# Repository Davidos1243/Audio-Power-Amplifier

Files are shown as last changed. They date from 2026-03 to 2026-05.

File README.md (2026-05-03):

# High-Fidelity Audio Power Amplifier (Class AB)





## 📌 Project Overview
This project involves the complete design, simulation, and PCB layout of a **Class AB audio power amplifier** designed specifically for high-frequency speakers (tweeters). The system is built around the Texas Instruments **LM3886** power amplifier IC and features active filtering using the **OPA2134** SoundPlus™ audio operational amplifiers.

### Key Features:
- **Output Power:** 60 W into an 8 Ω load.
- **Amplifier Class:** Class AB.
- **Active Crossover (Filters):**
  - High-Pass Filter (HPF) cutoff frequency: ~400 Hz.
  - Low-Pass Filter (LPF) cutoff frequency: ~20 kHz.
- **Input:** Standard 3.5mm audio jack (PC/Laptop sound card level).
- **Volume Control:** Integrated variable gain stage in the preamplifier.
- **Protection:** Built-in overvoltage, undervoltage, and SPiKe thermal protection (via LM3886).

---

## 📐 Design & Specifications

### Power Calculations
To achieve the target 60 W continuous output power for an 8 Ω speaker:
- Target speaker current: `I_rms ≈ 2.74 A`
- Target speaker voltage: `V_rms ≈ 21.91 V`
- Voltage gain required (for a 1 V input): `G ≈ 21.9 V/V`
- Power Supply: Symmetrical **±35 V** DC.
- Calculated maximum output power: `P_out ≈ 72 W` (providing safe headroom for the 60 W requirement).

### Component Selection
1. **Power Stage (LM3886):** Chosen for its high continuous average output power (up to 68 W), ultra-low distortion (0.03% THD+N), and robust SPiKe protection circuitry.
2. **Pre-amp & Active Filters (OPA2134):** Selected for its true FET-input, extremely low distortion (0.00008%), and excellent dynamic behavior tailored for high-end audio applications.

---

## 💻 LTspice Simulation
Before moving to physical design, the entire circuit was simulated in LTspice to verify stability, frequency response, and power efficiency.

### 1. Frequency Filters (Bode Analysis)
- **High-Pass Filter (Sallen-Key):** 2nd-order active filter. Simulated cutoff frequency (`f_c`) ≈ **399.6 Hz** with a stopband roll-off of -40 dB/decade.
- **Low-Pass Filter:** 2nd-order active filter. Simulated cutoff frequency (`f_c`) ≈ **20.8 kHz** with a stopband roll-off of -40 dB/decade.

### 2. Transient & Power Analysis
- Simulated using a 1 kHz sine wave input.
- Input voltage: `1 V` | Output voltage: `~32 V` (peak).
- Verified the required 60 W average power on the 8 Ω load.
- **Calculated Efficiency:** `η ≈ 71%` (at maximum power output).

---

## 🖨️ PCB Design (KiCAD)
The schematic was transferred to KiCAD for PCB layout. The physical layout was designed with strict analog audio guidelines:
- **Signal Flow:** Left-to-right signal path to prevent interference.
- **Trace Widths:** Calculated and adjusted for high-current power and output lines.
- **Grounding:** Large copper ground planes implemented to minimize noise and improve shielding.
- **Thermal Management:** Dedicated space and mounting holes provided for the LM3886 heatsink.
- **I/O:** Strategic placement of the 3.5mm jack, power terminals, and output connectors at the board edges.
- Form Factor: 2-layer FR-4 board, 50.8 x 48.26 mm.

---

## 🛠️ Bill of Materials (BOM)
Key components used in this design (SMD 0805 for passives to maintain a compact footprint):
- **ICs:** 1x LM3886, 2x OPA2134
- **Capacitors (SMD):** 1 nF, 2.2 nF, 100 nF, 120 nF, 220 nF, 1 µF
- **Resistors (SMD):** 100 Ω, 366.9 Ω, 500 Ω, 1.8 kΩ, 2 kΩ, 3.9 kΩ, 6.8 kΩ
- **Connectors:** 3.5mm Audio Jack, Molex SL Screw Terminals
- **Controls:** 10 kΩ THT Potentiometer for volume control

## 📦 Manufacturing
The PCB was cost-analyzed and prepared for fabrication using **JLCPCB** specifications:
- **Material:** FR4-TG135 (1.6mm thickness)
- **Copper Weight:** 1 oz
- **Surface Finish:** HASL

---

## 👨‍💻 Author
**Davyd Tkalich**  
*Electrical and Computer Engineering | Hardware Design Enthusiast*  
[LinkedIn](https://linkedin.com/in/davyd-tkalich-41916b277) | Edmonton, AB, Canada

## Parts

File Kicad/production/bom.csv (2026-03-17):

Designator | Footprint | Quantity | Value | LCSC Part #
C1, C10, C7, C9 | 0805 | 4 | 1u
C2 | 0805 | 1 | 1n
C3 | 0805 | 1 | 2.2n
C4 | 0805 | 1 | 220n
C5 | 0805 | 1 | 120n
C6, C8 | 0805 | 2 | 100n
J1 | Jack_3.5mm_CUI_SJ1-3533NG_Horizontal | 1 | AudioJack2
J2, J3 | Molex_SL_171971-0003_1x03_P2.54mm_Vertical | 2 | Screw_Terminal_01x03
J4 | Molex_SL_171971-0002_1x02_P2.54mm_Vertical | 1 | Screw_Terminal_01x02
R1, R8 | 0805 | 2 | 2k
R11 | 0805 | 1 | 8
R2 | 0805 | 1 | 0.5k
R3, R6 | 0805 | 2 | 3.9k
R4 | 0805 | 1 | 6.8k
R5 | 0805 | 1 | 1.8k
R7 | 0805 | 1 | 366.9
R9 | 0805 | 1 | 100
RV1 | Potentiometer_ACP_CA14-H4_Horizontal | 1 | 10k
U1, U3 | SOIC-8-1EP_3.9x4.9mm_P1.27mm_EP2.29x3mm | 2 | OPA2134
U2 | TO-220F-11_P3.4x5.08mm_StaggerOdd_Lead5.08mm_Vertical | 1 | LM3886

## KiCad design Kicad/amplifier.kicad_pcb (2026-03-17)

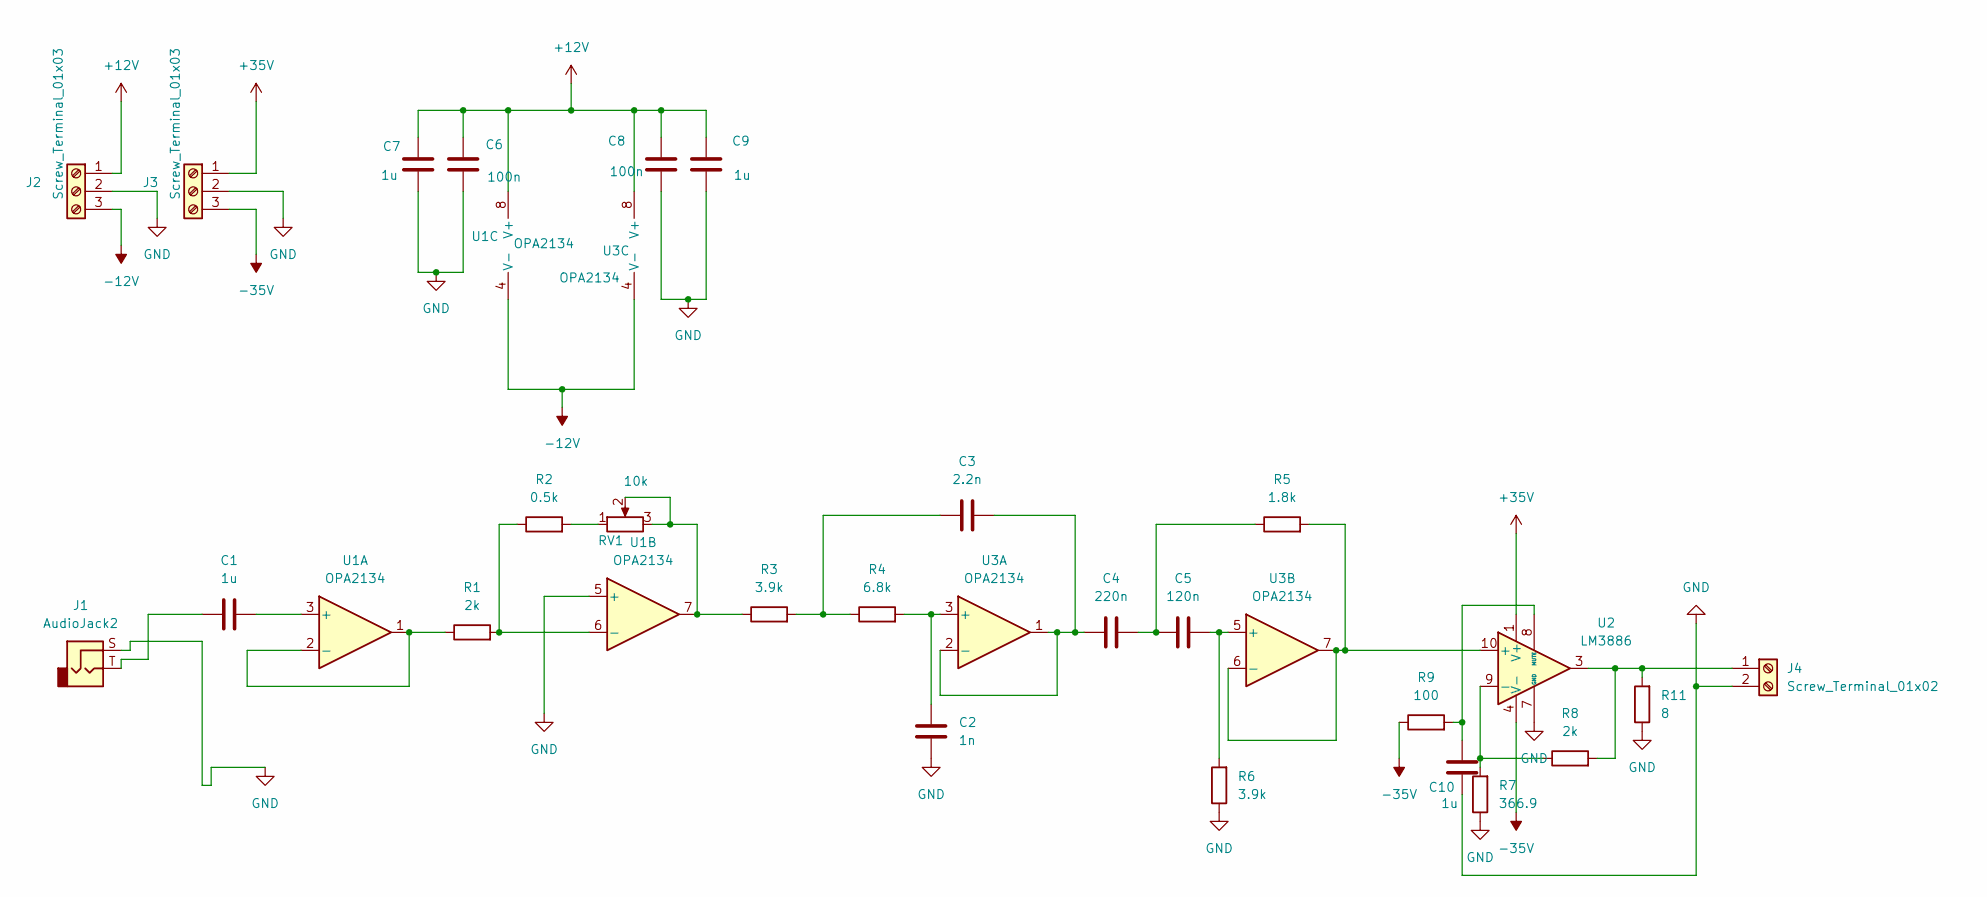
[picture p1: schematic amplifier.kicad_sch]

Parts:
C1, C7, C9, C10: 1u; C_0805_2012Metric
C2: 1n; C_0805_2012Metric
C3: 2.2n; C_0805_2012Metric
C4: 220n; C_0805_2012Metric
C5: 120n; C_0805_2012Metric
C6, C8: 100n; C_0805_2012Metric
J1: AudioJack2; Jack_3.5mm_CUI_SJ1-3533NG_Horizontal
J2, J3: Screw_Terminal_01x03; Molex_SL_171971-0003_1x03_P2.54mm_Vertical
J4: Screw_Terminal_01x02; Molex_SL_171971-0002_1x02_P2.54mm_Vertical
R1, R8: 2k; R_0805_2012Metric_Pad1.20x1.40mm_HandSolder
R2: 0.5k; R_0805_2012Metric_Pad1.20x1.40mm_HandSolder
R3, R6: 3.9k; R_0805_2012Metric_Pad1.20x1.40mm_HandSolder
R4: 6.8k; R_0805_2012Metric_Pad1.20x1.40mm_HandSolder
R5: 1.8k; R_0805_2012Metric_Pad1.20x1.40mm_HandSolder
R7: 366.9; R_0805_2012Metric_Pad1.20x1.40mm_HandSolder
R9: 100; R_0805_2012Metric_Pad1.20x1.40mm_HandSolder
R11: 8; R_0805_2012Metric_Pad1.20x1.40mm_HandSolder
RV1: 10k; Potentiometer_ACP_CA14-H4_Horizontal
U1, U3: OPA2134; SOIC-8-1EP_3.9x4.9mm_P1.27mm_EP2.29x3mm
U2: LM3886; TO-220F-11_P3.4x5.08mm_StaggerOdd_Lead5.08mm_Vertical

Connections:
+12V: C6.1, C7.1, C8.1, C9.1, J2.1, U1.8 (V+), U3.8 (V+)
+35V: J3.1, U2.1 (V+), U2.5 (V+)
-12V: J2.3, U1.4 (V-), U3.4 (V-)
-35V: J3.3, R9.1, U2.4 (V-)
GND: C2.2, C6.2, C7.2, C8.2, C9.2, C10.2, J1.S, J2.2, J3.2, J4.2, R6.1, R7.1, R11.1, U1.5 (+), U2.7 (GND)
unnamed: C1.1, J1.T
unnamed: C3.2, R3.2, R4.1
unnamed: C4.1, C5.2, R5.1
unnamed: J4.1, R8.2, R11.2, U2.3
unnamed: R2.2, RV1.1
unnamed: R3.1, RV1.2, RV1.3, U1.7
unnamed: C1.2, U1.3 (+)
unnamed: R1.1, U1.1, U1.2 (-)
unnamed: R1.2, R2.1, U1.6 (-)
unnamed: R5.2, U2.10 (+), U3.6 (-), U3.7
unnamed: R7.2, R8.1, U2.9 (-)
unnamed: C10.1, R9.2, U2.8 (MUTE)
unnamed: C2.1, R4.2, U3.3 (+)
unnamed: C3.1, C4.2, U3.1, U3.2 (-)
unnamed: C5.1, R6.2, U3.5 (+)

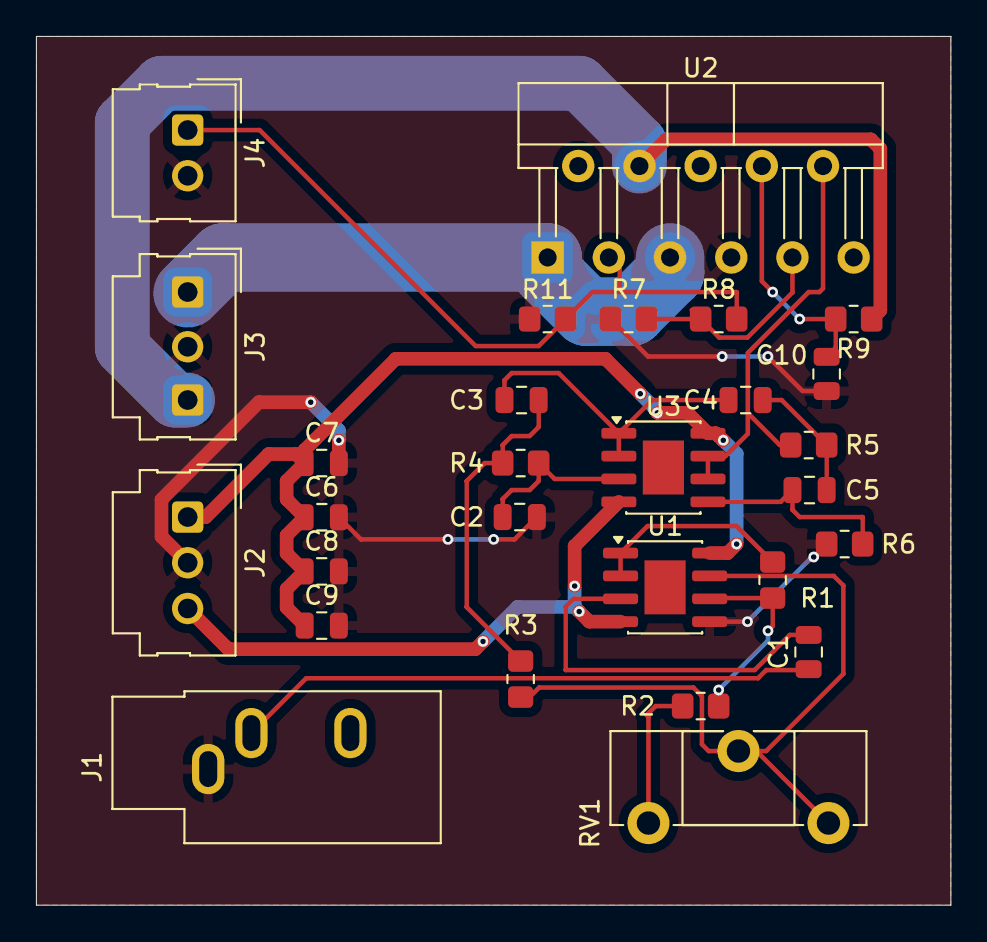
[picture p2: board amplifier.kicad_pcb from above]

Board: 2 copper layers, 50.8 x 48.3 mm, 28 parts (0 on the bottom side), 20 nets.

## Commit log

2026-03-17 Revise README for High-Fidelity Audio Power Amplifier
    Updated project title and enhanced project overview with detailed specifications, design, simulation, and manufacturing information for a high-fidelity audio power amplifier.
2026-03-17 Initial commit of all project files
    [amplifier.kicad_pcb, amplifier.kicad_sch, bom.csv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]
